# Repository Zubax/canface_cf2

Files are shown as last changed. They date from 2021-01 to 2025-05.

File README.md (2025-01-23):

# Babel-Babel

All-in-one hardware solution for developing [Cyphal/CAN](https://opencyphal.org) and DroneCAN devices.

Babel-Babel consists of three devices that are assembled on a single PCB:
2x [Babel](https://zubax.com/babel) USB-CAN adapters and a
[Dronecode probe](https://shop.zubax.com/collections/development-tools/products/dronecode-probe-v2-2-jtag-swd-adapter-usb-uart-adapter-with-dcd-m-cable)
(a generic JTAG/SWD + UART console adapter).

Babel-Babel is connected to the PC with a single USB cable as it contains a built-in USB hub.
It provides the following interfaces for connecting to the device under development:

- CAN 1 (UCANPHY Micro connector)
- CAN 2 (UCANPHY Micro connector)
- SWD and UART (Dronecode Debug connector, medium)
- USB (regular USB A connector)

Along with that, all these interfaces are routed to additional PLS connectors (regular 0.1' single-row pin headers).
These connectors may be used for production testing purposes.

Each Babel can be turned off using the corresponding dip switch.

For technical characteristics, please refer to [requirements document](/docs/requirements.md).

## Standalone debug tool

When the device is used as a standalone debug tool (when the pin headers are not used),
Babel-Babel is constructed using a "novel approach" often called oreo-construction.
This approach eliminates the need for having separate housing,
reliably protecting all the electronics inside the device
while also providing a possibility to deposit some explanatory notes on the top surface of the device
(like the purpose of connectors, pinouts, etc.) without any additional technological processes,
which allows Babel-Babel to be a relatively self-documenting device.

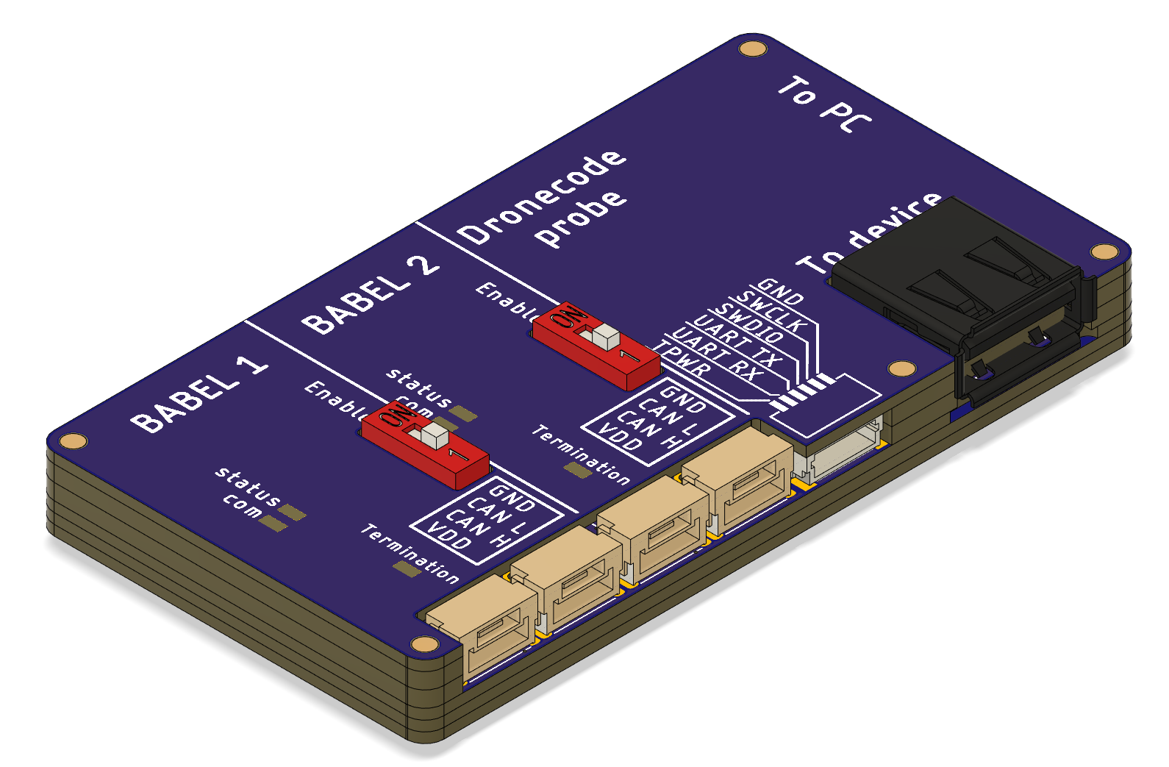
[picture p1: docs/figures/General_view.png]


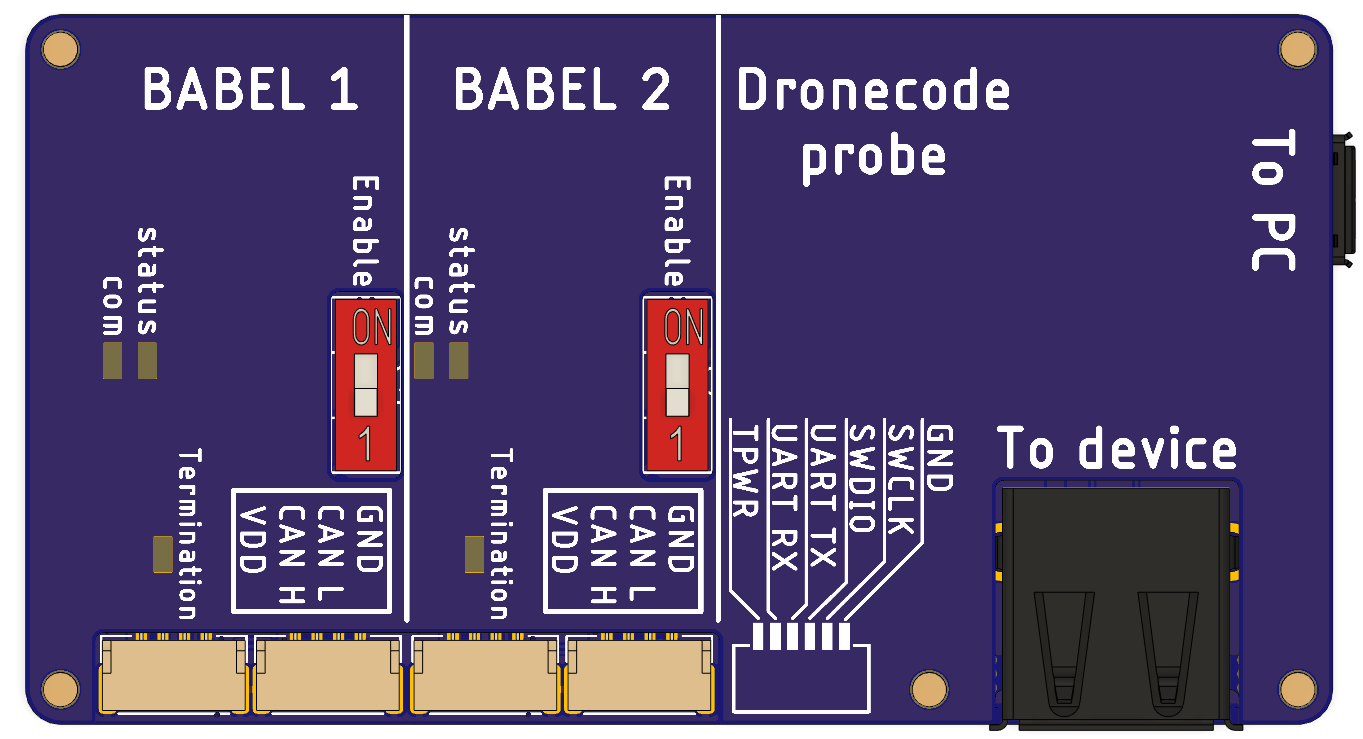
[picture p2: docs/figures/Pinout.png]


## Production flashing tool

To use Babel-Babel as a production flashing and testing tool, an adapter PCB should be designed.
In general, such PCB should have PBS connectors for Babel-Babel on one side and some connectors
for the device under test (usually pogo pins).
Both Babel-Babel and the device under test can then be connected to this adapter PCB and
the flashing and testing routine can be performed.

Although using Babel-Babel for testing requires some preparations,
it still may be beneficial as it greatly reduces the total amount of
wiring and connectors involved in the production testing routine.
This, in turn, makes the process faster, more reliable, and less painstaking.

The [Mitochondrik-LV](https://zubax.com/mitochondrik-lv) evaluation board is a good example.
To eliminate additional adapter PCBs, the evaluation board is designed to host Babel-Babel directly:

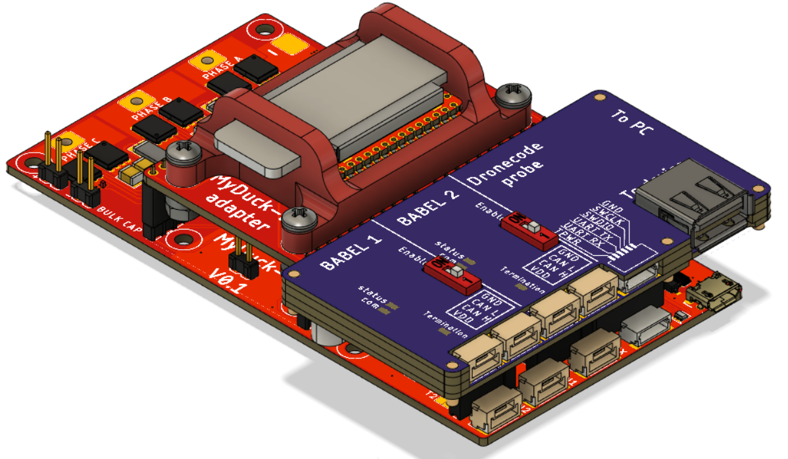
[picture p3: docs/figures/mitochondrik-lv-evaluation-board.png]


## Manufacturing instructions

For details on the manufacturing process of the device, check the
instructions at [manufacturing document](/docs/manufacturing.md).

## Release notes

Newest entries at the top.

### v1.3 (2025)

* Flip the two rest switches.
* Replaced obsolete part:

| Original | Alternative |
| --- | --- |
| NS5B1G385DTT1G | 74AHC1G66GV,125 |

### v1.2.2 (2023)

* Added alternative part:

| Original | Alternative |
| --- | --- |
| 74LVC2T45DC,125 | 74LVC2T45DC-Q100H |

### v1.2.1 (2023)

* Replaced Parts A, C, and D (spacer) PCBs with 3D.
* Added the Zubax logo to the enclosure PCB.

### v1.2 (2023)

* Fixed silkscreen labels and BOM inconsistencies.
* Replaced references to UAVCAN with Cyphal/CAN.

### v1.1 (2023)

* CAN VDD pulled high with resistor.
* Bootloader switch added to DCP with added pulup resistor.
* CAN VBUS voltage measurement implemented.

### v1.0 (2021)

The original version.

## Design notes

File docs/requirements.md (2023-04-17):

# Business requirements for Babel-Babel

## Purpose

Babel-Babel is a device intended to ease the process of flashing and testing of Zubax products (or similar products).
Besides that, the device can be used as a tool for developing and debugging Cyphal/CAN-compatible embedded devices.
One Babel-Babel can replace two USB-CAN converters, a programmer, and provide one free USB 2.0 host port.
All this requires a single USB connection to the host PC.

## Technical requirements

* Small size.
* Minimizing the number of required USB connections to the host PCB.
* Minimizing the number of required cable connections to the device under test.
* The hardware should be compatible with the existing software for Babel and DCP 2.x.

## Design requirements

* USB connectors should be able to tolerate moderate mechanical abuse.
* Enclosure class IP40.
* Standard Dronecode connector should be used for SWD interface and debug UART.
* USB-CAN converters should be compatible with Dronecode DS-015 hardware design recommendations.
* The device should be powered from the USB bus (4.5 - 5.5 V, current consumption up to 500 mA).
* Usage of non-AEC-Q grade components, as well as deviations from the hardware development policies, are allowed.

## Environmental conditions

* In-door usage.
* Operating temperature range - 0..+40C
* Operating humidty - up to 100% (non-condensing)

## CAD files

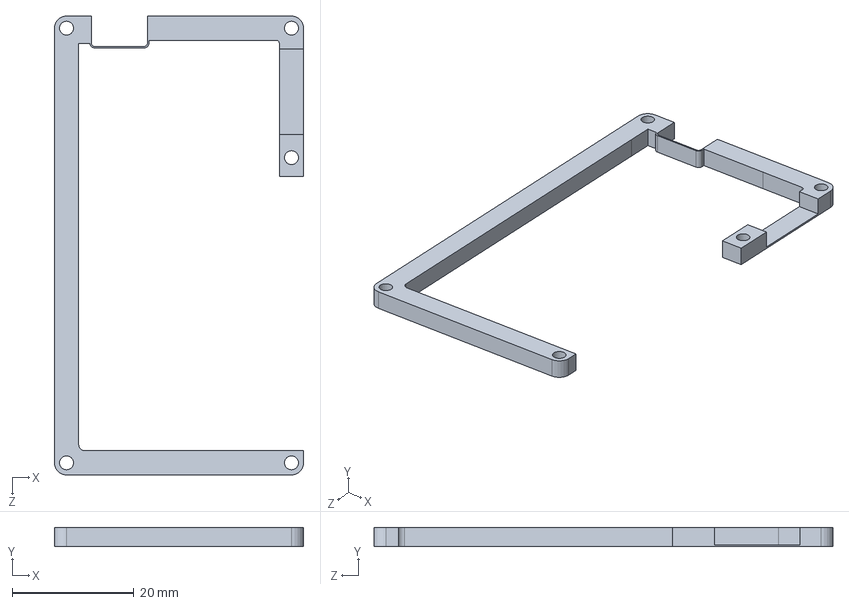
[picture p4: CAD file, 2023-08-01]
src/spacers.SLDPRT
41.0 x 3.20 x 75.5 mm

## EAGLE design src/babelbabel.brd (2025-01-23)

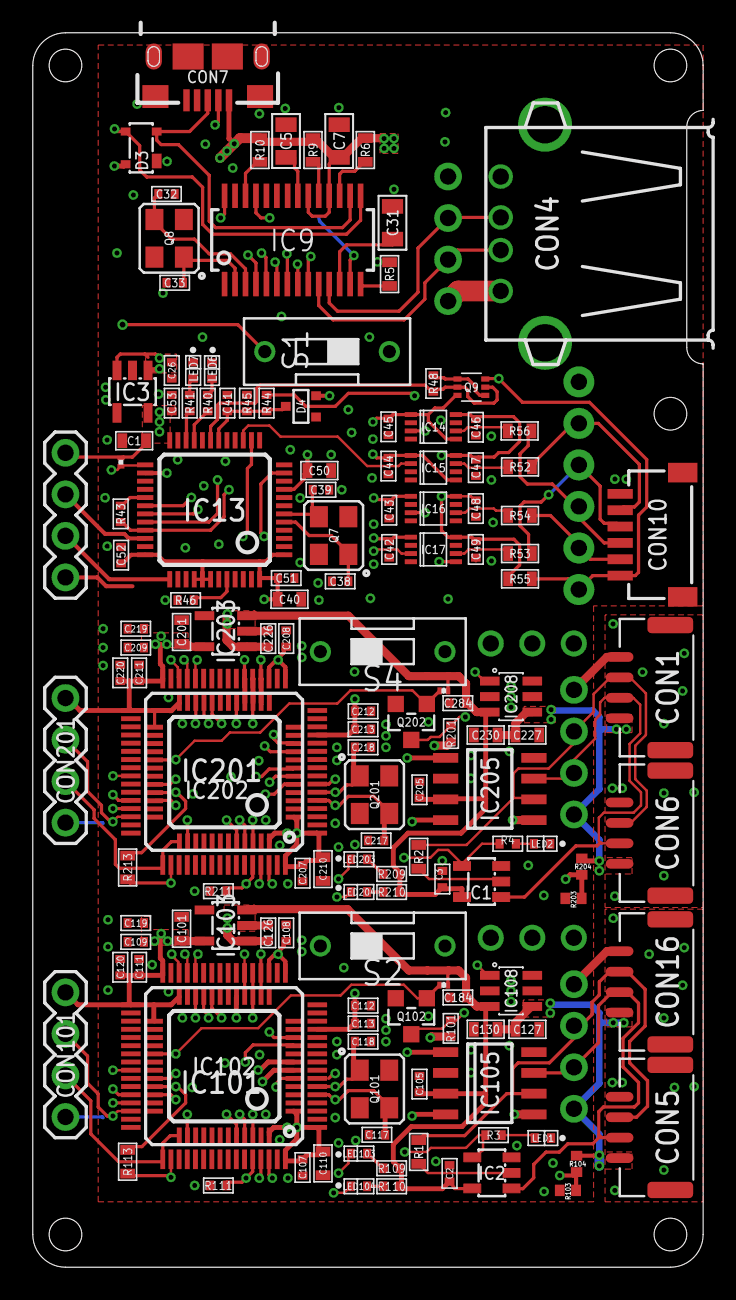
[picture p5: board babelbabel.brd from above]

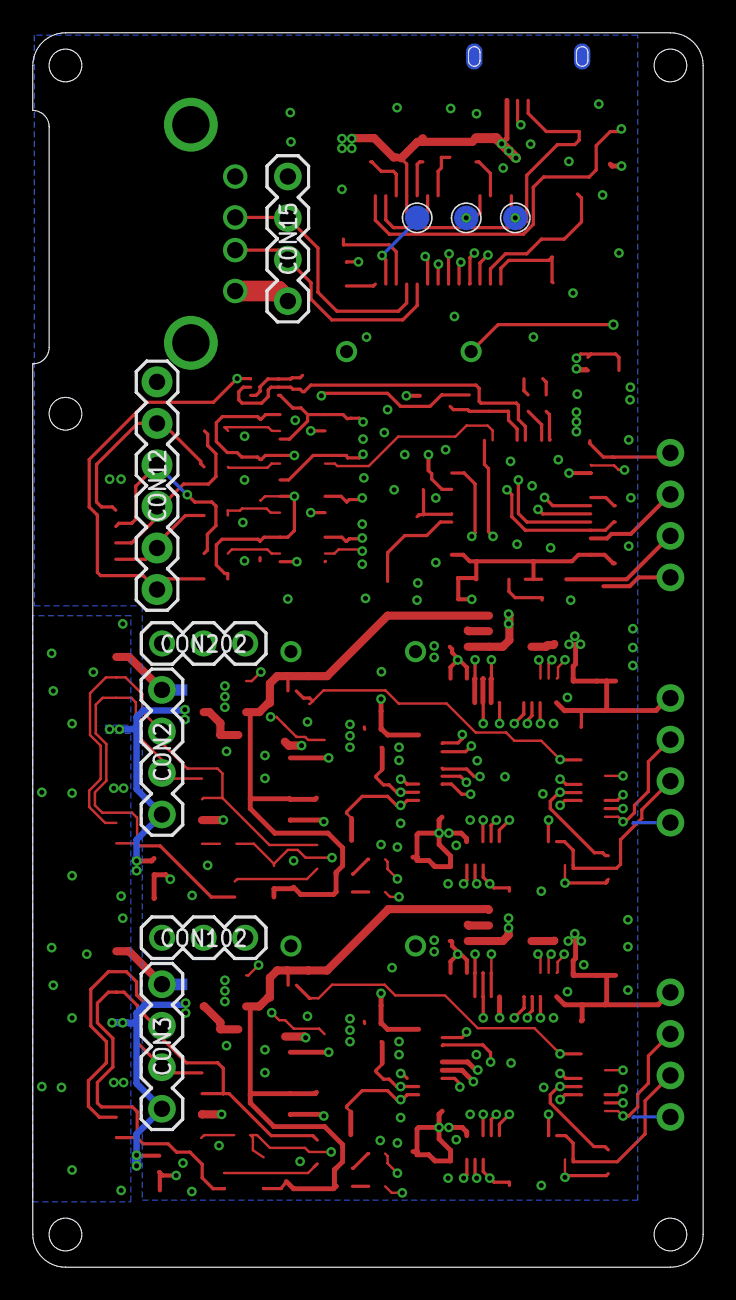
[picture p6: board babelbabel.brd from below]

Board: 4 copper layers, 41.0 x 75.5 mm, 156 parts (11 on the bottom side), 106 nets.

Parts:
C1, C40, C50, C101, C110, C127, C130, C201, C210, C227, C230: 4.7uF; C0603
C2, C3, C41, C42, C43, C44, C45, C46, C47, C48, C49, C51, C52, C53, C105, C107, C108, C184, C205, C207, C208, C284: 0.1uF; C0402
C5, C7, C31: 10uF; C0805
C26, C112, C119, C120, C126, C212, C219, C220, C226: 1uF; C0402
C32, C33, C117, C118, C217, C218: 20pF; C0402
C38, C39: 10pF; C0402
C109, C111, C113, C209, C211, C213: 10nF; C0402
CON1, CON5, CON6, CON16: CON-4P-TABS-JST_GH-RA; JST_GH-4P-RA
CON2, CON3, CON11, CON15, CON101, CON201: PINHEAD_1X04-2.54; 1X04-PTH-2.54
CON4: USB-AA-PTH; USB-A-F-PTH
CON7: USB-1; MICRO_USB_PEGS
CON10: CON-6P-SM06B; SM06B
CON12: PINHEAD_1X06-2.54; 1X06-PTH-2.54
CON102, CON202: PINHEAD_1X03-2.54; 1X03-PTH-2.54
D3: PRTR5V0U2X; SOT143B
D4: BAT54SWT1G; SC70
IC1, IC2: NS5B1G385; SOT23-5L
IC3, IC103, IC203: AP2127-3.3; SOT23-5
IC9: FE1.1S; SSOP-28
IC13: STM32F103CBT7; LQFP48
IC14, IC15, IC16, IC17: 74LVC2T45; VSSOP8
IC101, IC201: STM32F373CBT6-LQFP48; LQFP48
IC102, IC202: STM32F373RCT6; TQFP64
IC105, IC205: TJA1051-SO8; SOIC8
IC108, IC208: TPD3S014DBVR-SOT23-6; SOT26
J1, J2: CONNECTION-SMD; CONNECTION
LED1, LED2, LED6, LED7, LED103, LED104, LED203, LED204: LED-0402; LED0402
PAD1, PAD2, PAD4: PAD-S_2X2; 2х2
Q7: 8MHz; OSCILLATOR-3.2X2.5-4P
Q8: 12MHz; OSCILLATOR-3.2X2.5-4P
Q9: NTZD3152PT1G; SOT-563
Q101, Q201: 16MHz; OSCILLATOR-3.2X2.5-4P
Q102, Q202: 2N7002; SOT23
R1, R2, R52, R53, R54, R55, R56: 120R; R0603
R3, R4, R40, R41, R109, R110, R209, R210: 1K; R0402
R5: 2.7K; R0603
R6, R9, R10: 100K; R0603
R8, R102, R202: 10k; R0201
R43: 1K5; R0402
R44: 4K7; R0402
R45, R46, R48, R101, R111, R201, R211: 10K; R0402
R103, R104, R203, R204: 10k; R0402
R113, R213: 1K5; R0603
S1, S2, S4: DS01-STRAIGHT; DS-01

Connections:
BABEL1:BOOT0: IC101.44, IC102.60, R111.2
BABEL1:CAN_COMM: IC101.22, IC102.30, LED104.C
BABEL1:CAN_RX: IC101.45, IC102.61, IC105.4
BABEL1:CAN_STATUS: IC101.21, IC102.29, LED103.C
BABEL1:CAN_TX: IC101.46, IC102.62, IC105.1
BABEL1:CAN_VDD_EN: IC101.29, IC102.41, Q102.1, R102.1
BABEL1:N$1: IC108.1, Q102.3, R101.1
BABEL1:N$4: IC101.10, R103.1, R104.2
BABEL1:N$27: LED103.A, R109.1
BABEL1:N$28: LED104.A, R110.1
BABEL1:PA4: CON102.3, IC101.14, IC102.20
BABEL1:PA5: CON102.2, IC101.15, IC102.21
BABEL1:PA6: CON102.1, IC101.16, IC102.22
BABEL1:PF0: C117.2, IC101.5, IC102.5, Q101.3
BABEL1:PF1: C118.2, IC101.6, IC102.6, Q101.1
BABEL1:SWCLK: CON101.2, IC101.37, IC102.49
BABEL1:SWDIO: CON101.3, IC101.34, IC102.46
BABEL1:USB_PU: IC101.38, IC102.50, R113.2
BABEL1:VDD_3V3: C101.2, C107.1, C108.1, C109.2, C110.1, C111.2, C112.2, C113.2, C119.2, C120.2, CON101.4, IC101.1, IC101.9, IC101.17, IC101.24, IC101.25, IC101.48, IC102.1, IC102.13, IC102.17, IC102.19, IC102.32, IC102.33, IC102.64, IC103.5, IC105.5, R101.2
BABEL1_RST: IC101.7, IC102.7, S2.1
BABEL1_RST1: IC201.7, IC202.7, S4.1
BABEL1_TERM: IC2.4, IC101.20, IC102.28, R3.2
BABEL1_USB_N: IC9.4, IC101.32, IC102.44
BABEL1_USB_P: IC9.5, IC101.33, IC102.45, R113.1
BABEL2:BOOT0: IC201.44, IC202.60, R211.2
BABEL2:CAN_COMM: IC201.22, IC202.30, LED204.C
BABEL2:CAN_RX: IC201.45, IC202.61, IC205.4
BABEL2:CAN_STATUS: IC201.21, IC202.29, LED203.C
BABEL2:CAN_TX: IC201.46, IC202.62, IC205.1
BABEL2:CAN_VDD_EN: IC201.29, IC202.41, Q202.1, R202.1
BABEL2:N$1: IC208.1, Q202.3, R201.1
BABEL2:N$4: IC201.10, R203.1, R204.2
BABEL2:N$27: LED203.A, R209.1
BABEL2:N$28: LED204.A, R210.1
BABEL2:PA4: CON202.3, IC201.14, IC202.20
BABEL2:PA5: CON202.2, IC201.15, IC202.21
BABEL2:PA6: CON202.1, IC201.16, IC202.22
BABEL2:PF0: C217.2, IC201.5, IC202.5, Q201.3
BABEL2:PF1: C218.2, IC201.6, IC202.6, Q201.1
BABEL2:SWCLK: CON201.2, IC201.37, IC202.49
BABEL2:SWDIO: CON201.3, IC201.34, IC202.46
BABEL2:USB_PU: IC201.38, IC202.50, R213.2
BABEL2:VDD_3V3: C201.2, C207.1, C208.1, C209.2, C210.1, C211.2, C212.2, C213.2, C219.2, C220.2, CON201.4, IC201.1, IC201.9, IC201.17, IC201.24, IC201.25, IC201.48, IC202.1, IC202.13, IC202.17, IC202.19, IC202.32, IC202.33, IC202.64, IC203.5, IC205.5, R201.2
BABEL2_TERM: IC1.4, IC201.20, IC202.28, R4.2
BABEL2_USB_N: IC9.6, IC201.32, IC202.44
BABEL2_USB_P: IC9.7, IC201.33, IC202.45, R213.1
CAN1_VDD: C127.2, C130.2, CON3.1, CON5.1, CON16.1, IC108.4, R104.1
CAN1_VDD1: C227.2, C230.2, CON1.1, CON2.1, CON6.1, IC208.4, R204.1
CANH1: CON3.2, CON5.2, CON16.2, IC2.1, IC105.7
CANH2: CON1.2, CON2.2, CON6.2, IC1.1, IC205.7
CANL1: CON3.3, CON5.3, CON16.3, IC105.6, R1.2
CANL2: CON1.3, CON2.3, CON6.3, IC205.6, R2.2
CAN_L: IC2.2, R1.1
CONSOLE_RX: CON10.3, CON12.3, R56.2
CONSOLE_TX: CON10.2, CON12.2, R54.2
DCP_DM: IC9.8, IC13.32
DCP_DP: IC9.9, IC13.33, R43.2
DUT_DM: CON4.D-, CON15.2, IC9.10
DUT_DP: CON4.D+, CON15.3, IC9.11
GND: C1.1, C2.1, C3.1, C5.1, C7.1, C26.1, C31.1, C32.1, C33.1, C38.2, C39.2, C40.2, C41.1, C42.2, C43.2, C44.2, C45.2, C46.1, C47.1, C48.1, C49.1, C50.1, C51.2, C52.1, C53.2, C101.1, C105.1, C107.2, C108.2, C109.1, C110.2, C111.1, C112.1, C113.1, C117.1, C118.1, C119.1, C120.1, C126.1, C127.1, C130.1, C184.2, C201.1, C205.1, C207.2, C208.2, C209.1, C210.2, C211.1, C212.1, C213.1, C217.1, C218.1, C219.1, C220.1, C226.1, C227.1, C230.1, C284.2, CON4.GND, CON7.GND, CON7.GND1, CON7.GND2, CON7.GND3, CON7.GND4, CON7.P$1, CON7.P$2, CON7.P$3, CON7.P$4, CON10.6, CON10.G1, CON10.G2, CON11.1, CON12.6, CON15.4, CON101.1, CON201.1, D3.1, D4.1, IC1.3, IC2.3, IC3.2, IC9.1, IC13.8, IC13.23, IC13.35, IC14.2, IC14.4, IC14.7, IC15.4, IC16.4, IC16.5, IC17.2, IC17.4, IC17.7, IC101.8, IC101.23, IC101.47, IC102.12, IC102.31, IC102.63, IC103.2, IC105.2, IC105.8, IC108.2, IC201.8, IC201.23, IC201.47, IC202.12, IC202.31, IC202.63, IC203.2, IC205.2, IC205.8, IC208.2, J1.P$1, J2.P$1, LED1.C, LED2.C, LED6.C, LED7.C, Q7.2, Q7.4, Q8.2, Q8.4, Q101.2, Q101.4, Q102.2, Q201.2, Q201.4, Q202.2, R5.1, R45.1, R46.2, R103.2, R111.1, R203.2, R211.1, S1.1, S2.10, S4.10
GNDD: CON1.4, CON1.M$0, CON1.M$1, CON2.4, CON3.4, CON5.4, CON5.M$0, CON5.M$1, CON6.4, CON6.M$0, CON6.M$1, CON16.4, CON16.M$0, CON16.M$1, J1.P$2, J2.P$2
IRXD: IC13.31, IC16.3
ITCK: IC13.15, IC15.2
ITMS: IC13.14, IC17.3
ITMS_DIR: IC13.11, IC17.5
ITXD: IC13.30, IC14.3
LED1: IC13.21, R40.2
LED2: IC13.22, R41.2
unnamed: LED1.A, R3.1
unnamed: IC1.2, R2.1
unnamed: LED2.A, R4.1
unnamed: C31.2, IC9.12
unnamed: IC9.14, R5.2
unnamed: C33.2, IC9.2, Q8.1
unnamed: C32.2, IC9.3, Q8.3
unnamed: CON7.D+, D3.2, IC9.16
unnamed: CON7.D-, D3.3, IC9.15
unnamed: IC9.26, R10.1
unnamed: C5.2, IC9.21
unnamed: IC9.17, R6.1
unnamed: IC9.19, R9.1
unnamed: IC9.25, PAD4.P$1
unnamed: IC9.13, PAD1.P$1
unnamed: IC9.28, PAD2.P$1
unnamed: C38.1, IC13.5, Q7.1
unnamed: C39.1, IC13.6, Q7.3
unnamed: LED6.A, R40.1
unnamed: LED7.A, R41.1
unnamed: IC13.29, R43.1
unnamed: IC13.44, R46.1
unnamed: Q9.1, Q9.4, R48.1
PWR_BR: IC13.19, Q9.2, Q9.5, R48.2
SWCLK: CON11.2, IC13.37
SWDIO: CON11.3, IC13.34
SWITCH: IC13.25, R8.1, S1.10
TCK: CON10.5, CON12.5, R52.2
TMS: CON10.4, CON12.4, R53.2
TPWR: CON10.1, CON12.1, Q9.6, R44.2, R55.2
VBUS3: C41.2, D4.3, IC13.18, R44.1, R45.2
VDD_3V3: C1.2, C40.1, C42.1, C43.1, C44.1, C45.1, C50.2, C51.1, C52.2, C53.1, CON11.4, D4.2, IC3.5, IC13.1, IC13.9, IC13.24, IC13.36, IC13.40, IC13.41, IC13.42, IC13.48, IC14.1, IC14.5, IC15.1, IC15.5, IC16.1, IC17.1, Q9.3, R8.2
VDD_5V: C2.2, C3.2, C7.2, C26.2, C105.2, C126.2, C184.1, C205.2, C226.2, C284.1, CON4.VBUS, CON7.VBUS, CON15.1, D3.4, IC1.5, IC2.5, IC3.1, IC3.3, IC9.18, IC9.20, IC13.26, IC103.1, IC103.3, IC105.3, IC108.3, IC203.1, IC203.3, IC205.3, IC208.3, R6.2, R9.2, R10.2, R102.2, R109.2, R110.2, R202.2, R209.2, R210.2
XRXD: IC16.6, R54.1
XTCK: IC15.7, R52.1
XTMS: IC17.6, R53.1
XTPWR: C46.2, C47.2, C48.2, C49.2, IC14.8, IC15.8, IC16.8, IC17.8, R55.1
XTXD: IC14.6, R56.1

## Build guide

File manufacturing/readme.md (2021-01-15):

# Babel-Babel manufacturing

The following operations must be performed for Babel-Babel manufacturing:

1) SMT mounting of the main PCB.

2) Flashing both Babels and [Dronecode probe](https://github.com/Zubax/dronecode_probe) on the PCB.
This operation should be performed without installing any connectors on the PCB,
a 4-pin pogo pin connector should be used instead.
Connectors' pinouts used for flashing can be found in the picture below.



3) After flashing is done, all the PCBs should be stacked, aligned,
and secured together using x5 2 mm diameter pins.
"Part A" PCBs should be split in two parts beforehand,
and the excessive material that interferes with USB A connector placement should be removed.
The pins can be manufactured by cutting widely available round wooden dowels 
with 2 mm diameter to appropriate length (7.7 mm).
The dowels can be purchased in general hardware stores 
or on [Amazon](https://www.amazon.co.uk/Wooden-Sticks-Round-Dowels-Natural/dp/B07T4ZFFHQ)
and other online shops.



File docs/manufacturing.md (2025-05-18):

# Babel-Babel manufacturing

## PCB specification for all PCB
### Main PCB

* Layers: 4 (layer stack in manufacturing package)
* Thickness: 1.0mm
* PCB color: Red
* Silkscreen: White
* Surface Finish: LeadFree HASL-RoHS
* Outer Copper Weight: 1 oz or 1.4 Mils
* Inner Copper Weight: 0.5 oz or 0.7 mils
* Material Type: FR4
* Flying Prob Test: Fully Test
* Castellated Holes: No

### Enclosure PCB

* Surface Finish: LeadFree HASL-RoHS
* Color: Red
* Silkscreen: White
* Material: FR4
* No Copper
* Thickness: 0.8mm

## Manufacturing

NOTE: When generating the gerber files, use the 2/2 DCP schematic.

1) SMT mounting of the main PCB.

2) Flashing both Babels and [Dronecode probe](https://github.com/Zubax/dronecode_probe) on the PCB.
This operation should be performed without installing any connectors on the PCB,
a 4-pin pogo pin connector should be used instead.
Connectors' pinouts used for flashing can be found in the picture below.



To flash Babel-Babel, the Babel part of the board has to be flashed first then the DCP part will be flashed.
To flash and test Babel, follow the procedure below:
* Turn off one babel by toggling the switch
* Connect 1 DCP and 1 Babel from PC
  
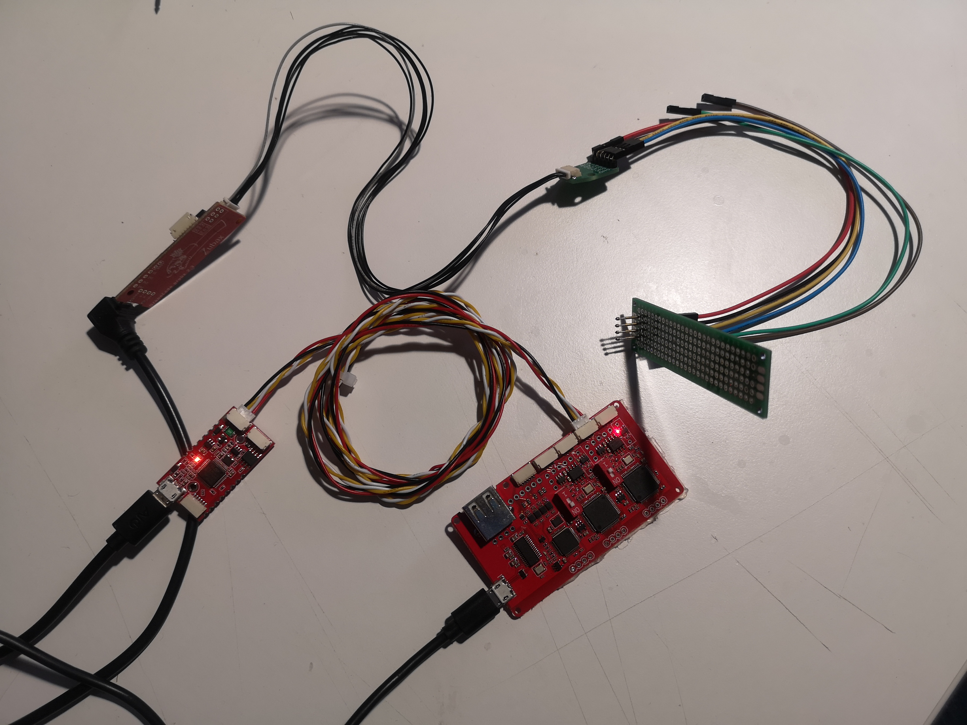
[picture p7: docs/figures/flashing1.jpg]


* Connect 1 CAN port from Babel to 1 port of Babel-Babel on the side that'll be flashed
* Navigate to drwatson_babel repository and run "./drwatson_babel.py (babel port path)"
 
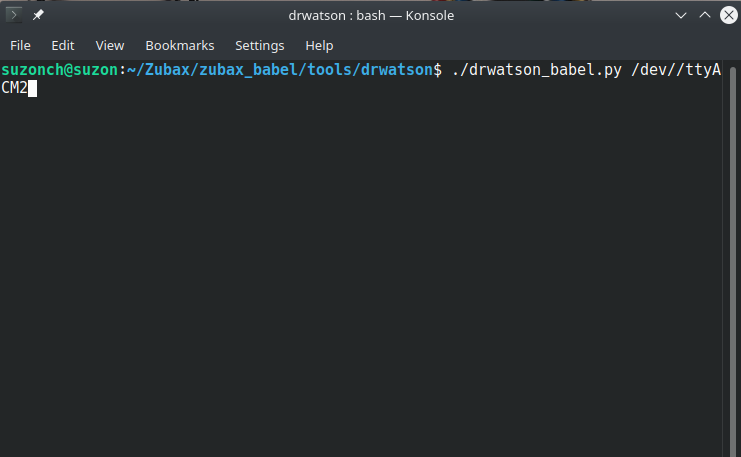
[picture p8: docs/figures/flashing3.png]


* Hold the pogo-pins from DCP to flashing interface of Babel-Babel

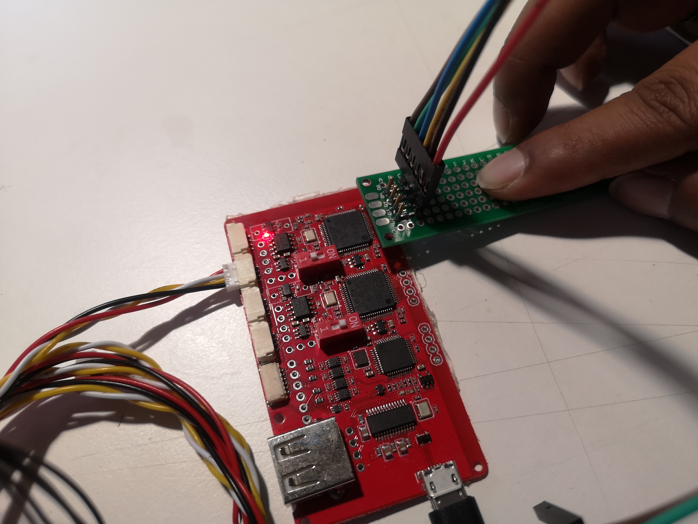
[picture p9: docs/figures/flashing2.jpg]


* Press enter and the flashing process will start

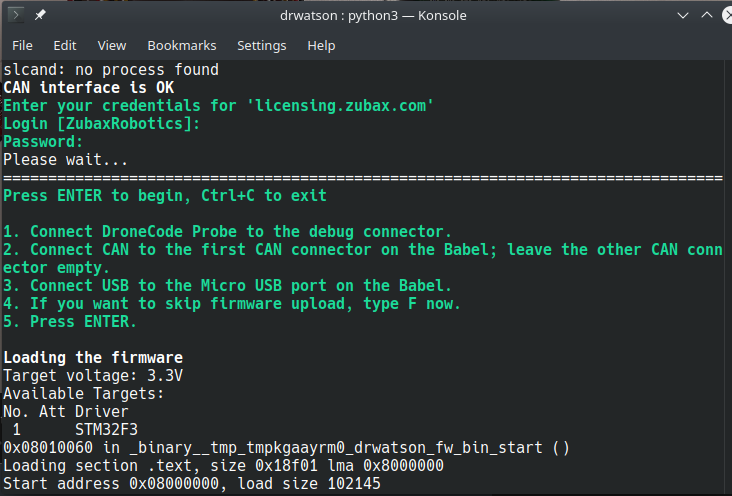
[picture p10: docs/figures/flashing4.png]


To flash the DCP part, follow [the DCP Manufacturing documentation](https://github.com/Zubax/dronecode_probe/blob/master/MANUFACTURING.md).

3) After flashing is done, the PCBs and 3D enclosure parts should be stacked, aligned,
and secured together using x5 M2x10 mm screws and nuts.
* For the top 3D spacer, insert the bottom connector in the gap underneath CON4.

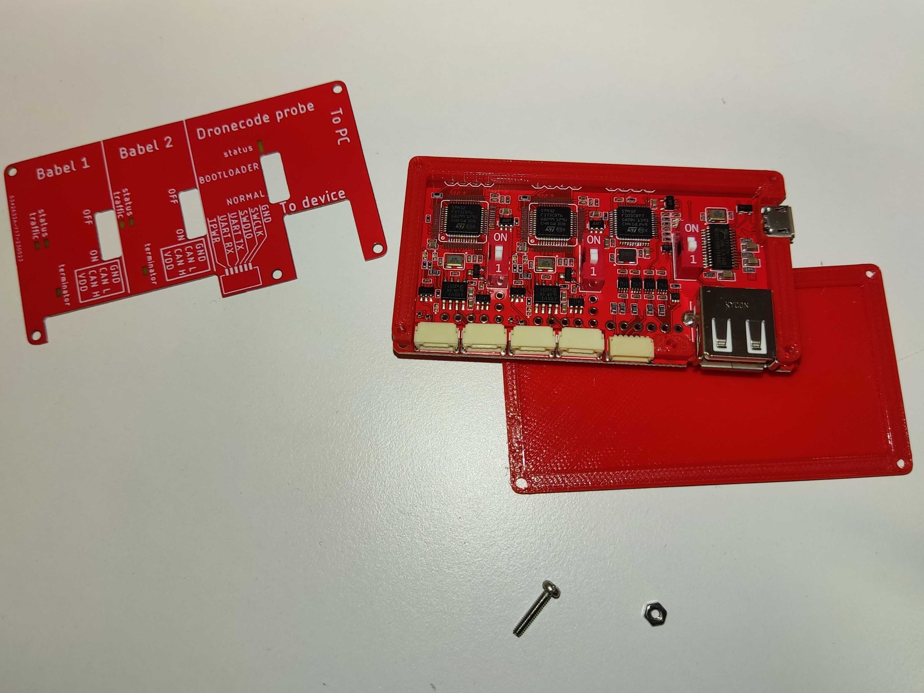
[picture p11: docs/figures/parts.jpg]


4) The final switch positions shall be as shown below:

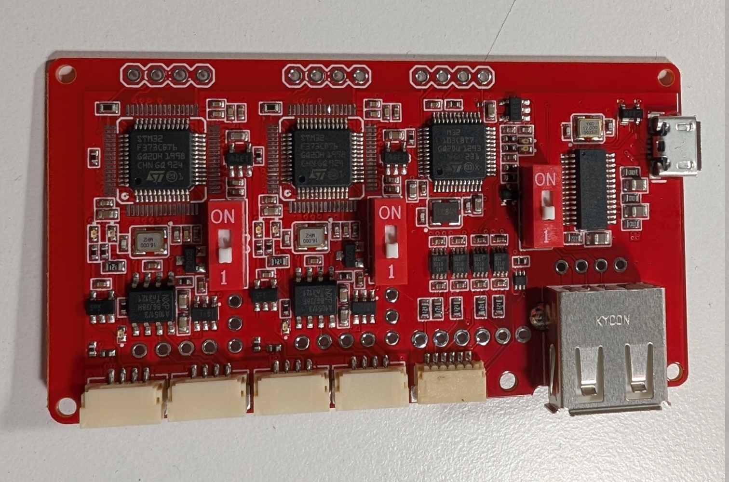
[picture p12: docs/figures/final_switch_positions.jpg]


## BOM for final assembly of Babel-Babel

| Name | Quantity |
| --- | --- |
| Enclosure PCB | 1 |
| Top 3D spacer | 1 |
| Main PCB | 1 |
| Bottom 3D spacer | 1 |
| M2x10 mm screws  | 5 |
| M2 nuts | 5 |

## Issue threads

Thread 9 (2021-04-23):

DCP enters the bootloader mode at first power on

pavel-kirienko, 2021-04-23:
The DCP tends to occasionally freeze up when high-voltage power is applied to the target with Babel-Babel connected. Steps to reproduce:

1. Connect Babel-Babel to the (unpowered) target via both CAN interfaces, the DCP port, and the USB.
2. Connect Babel-Babel to the USB host (in my case this is a USB hub with a dedicated wall power supply).
3. Apply high-voltage power to the target (Myxa B0 in my case).
4. Observe DCP disappear from the list of connected devices on the host.

It may take several attempts to reproduce the problem.

The issue affects none of the other three devices connected to Babel-Babel. The DCP can be brought back to life by physically re-connecting Babel-Babel to the host with the DCP port unplugged, and then plugging the DCP port back in.

I suggest equipping the DCP port with EMI mitigation measures, perhaps resistors or chokes. Also, increasing the decoupling capacitance on the MCU might help.

pavel-kirienko, 2021-10-18:
This is not an EMI problem, this is a schematics issue. The DCP starts the bootloader instead of launching the main firmware. It is designed to do so if the BOOT button is pressed at power on, so we should ensure that the button is routed correctly. Maybe its pin is left floating?

Closed 2023-02-02.

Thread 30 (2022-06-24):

Updating the DroneCode Probe firmware should not require diassembling the device

pavel-kirienko, 2022-06-24:
Currently, it is unclear how to reflash the DroneCode Probe without pulling the enclosure apart. Maybe we should add a button like in the original DCP?

Closed 2023-02-02.

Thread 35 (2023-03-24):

ERC Warnings & Part Number Check

Zentrus, 2023-03-24:
- [x] check R43 & R113, R213 - they have the same part number but different packages (402 & 603)
- [x] resolve ERC warnings in the schematic

suzonch, 2023-04-05:
R113 & R312 is  ERJ-3EKF1501V

R43 is 0402WGF1501TCE

Closed 2023-04-17.

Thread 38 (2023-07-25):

add Zubax logo to the enclosure PCB

Zentrus, 2023-07-25:
add the Zubax logo to the enclosure PCB - perhaps underneath "To PC" and above "To device"

Closed 2023-07-27.

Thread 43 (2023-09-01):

Flip the Babel reset switches

pavel-kirienko, 2023-09-01:
"ON" should mean on.

Closed 2023-09-07.

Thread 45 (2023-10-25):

add hole on the upper left corner of the enclosure PCB

Zentrus, 2023-10-25:
The enclosure PCB is missing one hole in the upper left corner for the bolts.

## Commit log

2020-12-21 initial import
    [babelbabel.brd, babelbabel.sch, part A.brd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]
2020-12-22 Routing seems done
    [babelbabel.brd, babelbabel.sch]
2020-12-23 excessive DCP nets removed
    [babelbabel.brd, babelbabel.sch]
2020-12-23 PLS connector for DCP connector rotated 180 degrees to match DCP connector
    [babelbabel.brd]
2020-12-25 SSOP28 footprint update
    [babelbabel.brd, babelbabel.sch]
2020-12-25 Silkscreen fix
    [babelbabel.brd]
2020-12-25 All doubtful issues resolved
    [babelbabel.brd, babelbabel.sch]
2020-12-25 CAN transciever replaced
    [babelbabel.brd, babelbabel.sch]
2020-12-25 Babel part attributes added
    [babelbabel.brd, babelbabel.sch]
2020-12-25 Massive attribute update
    [babelbabel.brd, babelbabel.sch]
2020-12-25 BOM improvement
    [babelbabel.brd, babelbabel.sch]
2020-12-28 UAVCAN PLS connectors fixed
    [babelbabel.brd, babelbabel.sch]
2020-12-28 Minor tweaks
    [babelbabel.brd, babelbabel.sch, part B.brd]
2020-12-28 all base features are now locked
    [babelbabel.brd]
2021-01-06 Analog switch added as alternative to mechanical switch for switching termination resistor in babel
    [babelbabel.brd, babelbabel.sch]
2021-01-06 DRC fixes
    [babelbabel.brd, babelbabel.sch]
2021-01-06 3d model updates
    [babelbabel.brd, babelbabel.sch]
2021-01-08 Create part B1.brd
    [part B1.brd]
2021-01-08 Update part B1.brd
    [part B1.brd]
2021-01-08 flashing connectors pinout added
    [babelbabel.brd, babelbabel.sch]
2021-01-15 Correct the docs (no substantial changes, mostly grammar and formatting) (#1)
    * Correct the docs (no substantial changes, mostly grammar and formatting)
    * Add links to Babel and DCP
    * Fixes for release preparation v0.1 (#3)
    * source files consistency fix
    * Delete part B.brd
    * Revert "Delete part B.brd"
    This reverts commit 4a45031003260e5b2cc94cb50fce3c8d96386cdc.
    * Revert "source files consistency fix"
    This reverts commit 015ba0159d9c48fa3345c98b8ff1ca9c9c6bfb7d.
    * fixes for https://github.com/Zubax/Babel-Babel/pull/1
    * Update readme.md
    * Update readme.md
    * Update manufacturing/readme.md
    * Upd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
    [babelbabel.brd, babelbabel.sch, part B.brd]
2021-01-29 Attribute updates for manufacturability (#4)
    [babelbabel.brd, babelbabel.sch]
2021-07-30 connected Vref to VDD, fixes #10 (#11)
    [babelbabel.brd, babelbabel.sch]
2021-08-04 Fixed mosfet Q2 from both babel, fixes #6 (#12)
    * removed mosfet Q2 from both babel, fixes #6
    * removed Q2
    * minor routing improvement
    * cutout for DCP LED
    * fixes #6
    * trace width fixes #6
    * ratnest fix, clean DRC
    [babelbabel.brd, babelbabel.sch, part B1.brd]
2021-08-13 Removed unnecessary assembly variant "mechanical terminator" fixes #13 (#15)
    * removed assembly variant mechanical terminator fixes #13
    * removed assembly variant Electronic terminator and components that were not in use, now we have default variant
    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
    [babelbabel.brd, babelbabel.sch]
2021-08-13 fixes switch label (#17)
    [part B1.brd]
2021-08-13 Revert "Fixed mosfet Q2 from both babel, fixes #6 (#12)"
    This reverts commit d39d7e4d46531cf5480a8d684ba2b4b43b92db19.
    [babelbabel.brd, babelbabel.sch, part B1.brd]
2021-08-13 Redoing past changes and new fixes (#20)
    * fixed mosfet Q2
    * fixed switch label in top board
    * removed unnecessary assembly variant
    [babelbabel.brd, babelbabel.sch, part B1.brd]
2021-08-13 changed footprint CON4 (#21)
    * changed footprint CON4
    * fixed wrong USB connection
    [babelbabel.brd, babelbabel.sch]
2021-10-08 64 pin swaped with 48 (#23)
    [babelbabel.brd, babelbabel.sch]
2023-02-02 CAN bus voltage measurement implemented #29 (#32)
    * CAN bus voltage measurement implemented #29
    * CAN_VDD_EN pulled up to 5v #28
    * #31 #30 #9
    * ready for review
    * minor changes
    * version text added
    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
    [babelbabel.brd, babelbabel.sch, part B1.brd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]
2023-02-03 rename board file (#33)
    [part B.brd]
2023-03-23 manufacturer fix, no electrical changes were done (#34)
    [babelbabel.brd, babelbabel.sch]
2023-04-17 v1.2 with fixes (#36)
    Fix #35
    Fix silkscreen labels
    Actualize the docs
    [babelbabel.brd, babelbabel.sch, part B.brd]
2023-07-27 Add Zubax logo to enclosure (#39)
    [part B.brd]
2023-08-01 new spacers & manufacturing instructions (#37)
    Alternative spacers for parts A & C - assembly with parts B & D remain
    the same
    [BABBAB-1]
    [BABBAB-1]:
    https://zubax.atlassian.net/browse/BABBAB-1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
    [part A.brd, part C.brd, part D.brd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]
2023-08-01 renamed part B to enclosure (#40)
    [enclosure.brd]
2023-08-31 added manufacturing note & alternative part (#42)
    will release the new manufacturing pack after this is merged
    [babelbabel.brd, babelbabel.sch]
2023-09-07 flip the rest switches (#44)
    [babelbabel.brd, babelbabel.sch]
2025-01-23 part number update & v1.3 mfgpack release (#47)
    NS5B1G385DTT1G is obsolete
    74AHC1G66GV,125 is a direct replacement
    will update manufacturing pack
    <!-- This is an auto-generated comment: release notes by coderabbit.ai
    -->
    ## Summary by CodeRabbit
    - **Documentation**
    - Updated README.md with release notes for v1.3
    - Added specific release year and component replacement details
    - **Chores**
    - Updated component attributes in schematic and board files
    - Replaced part numbers for components IC1 and IC2
    - Updated manufacturer information from ON Semiconductor to Nexperia USA
    Inc.
    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
    [babelbabel.brd, babelbabel.sch]
2026-03-27 New enclosure files (#50)
    [enclosure.brd, enclosure_back.kicad_pcb, enclosure_front.kicad_pcb]
2026-05-07 Fix holes orientation (#51)
    The last batch had the holes in the wrong orientation, resulting in the
    logo print being on the inside when mounted.
    (There was also a problem with the thickness which had to be 0.8mm
    instead of the standard 1.6mm.)
    [enclosure_back.kicad_pcb]
